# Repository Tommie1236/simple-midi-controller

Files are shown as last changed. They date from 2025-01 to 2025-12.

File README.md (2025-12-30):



# Simple MIDI Controller

### A simple 32-button MIDI controller with bank support, built around the RP2040 microcontroller (e.g., RP2040-Zero, but other RP2040 boards should work with appropriate pin changes). Designed for compatibility with any software that accepts USB MIDI input.
## Features

  32 configurable buttons
  Multiple banks for expanded control
  USB MIDI device class (works out-of-the-box with most DAWs and lighting control software)
  MAX7219 7-segment display for bank number
  LVGL graphics library integration for future graphical display support
  Example use: MyDMX, generic macropad for other MIDI-compatible software

## Hardware

  Primary target: RP2040-Zero
  Any RP2040-based board can be used (adjust pin mappings as needed)
  Wiring and assembly instructions: TODO!!

## Software Dependencies

  Raspberry Pi Pico SDK
  TinyUSB
  LVGL v9.4.0 (Light and Versatile Graphics Library)

## Building and Flashing

  Clone this repository and its dependencies.
  Build the firmware using the included build script in the root directory. 
  Optionally use the -l flag to automaticly use picotool to load it to the device.
  Or reboot into bootsel mode and drag the compiled binary(.uf2) onto the usb mass storage device. 

## Usage

Once flashed, the controller will appear as a standard USB MIDI device. It should work with any MIDI-compatible software. Currently tested with MyDMX, but suitable for general MIDI macro control.

For information about the LVGL graphics library integration, see [Code/LVGL_INTEGRATION.md](Code/LVGL_INTEGRATION.md).

Pin Configuration

  Default pin mappings are defined in the code for RP2040-Zero.
  If you use a different RP2040 board, update the pin definitions as needed in the source files.

## Roadmap

  - [x] implement segment display
  - [x] add banking support
  - [x] add LVGL graphics library for future graphical display/menu support
  - [ ] add a menu for configuration?
  - [ ] Add full hardware assembly and wiring instructions
  - [x] create pcb for easier replication without the big amount of soldering perfboard requires.
  - [x] ^ also schematic?
  
## Ai useage (hackclub Summer of Making)
I've used ai in this project. for example to create a base for this readme but i have also used some chatbots with high level debugging if i got stuck.
I've also had copilot enable in vscode when i started the project. but i've since switched to neovim and didn't add any ai or lsp yet. so mostly just high level debugging and writing text. (I'm very bad at this as you can probably already see.)
I really don't like using ai to generate code snippets. sometimes copilot is usefull when you need a lot of repeating code with just a simple parameter changing. But the rest of the time it is pretty useless imo and things like chatgpt/gemini make too many mistakes or inefficiencies to be usefull for snippets.

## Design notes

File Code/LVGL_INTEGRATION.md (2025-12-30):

# LVGL Integration for Simple MIDI Controller

This document describes the LVGL (Light and Versatile Graphics Library) integration for the Simple MIDI Controller project.

## Overview

LVGL v9.4.0 has been integrated into this project to provide graphical display capabilities. This integration provides a foundation for adding a graphical menu system and enhanced visual feedback beyond the MAX7219 7-segment display.

## Components

### 1. LVGL Library
- Added as a git submodule in `Code/lib/lvgl`
- Configured via `Code/lv_conf.h`
- Built as part of the main firmware build

### 2. Display Driver (`lvgl_display.c` / `lvgl_display.h`)
- Provides the interface between LVGL and display hardware
- Currently implements a stub driver that can be extended for actual display hardware
- Default resolution: 240x240 pixels (configurable in `lvgl_display.h`)
- Uses partial buffering for memory efficiency

### 3. UI Integration (`main.c`)
- LVGL initialization in `init_lvgl()`
- Periodic update via `lvgl_task()` called in main loop
- Example UI showing current bank number
- Bank number updates when bank buttons are pressed

## Configuration

The LVGL configuration file (`Code/lv_conf.h`) is optimized for the RP2040:

- **Color Depth**: 16-bit (RGB565)
- **Memory**: Uses standard C library malloc
- **Rendering**: Software rendering with no SIMD acceleration
- **Widgets**: Only essential widgets enabled (Label, Button, Arc, Bar, Image)
- **Demos/Examples**: Disabled to save flash space
- **Font**: Montserrat 14 enabled by default

## Memory Usage

The current firmware with LVGL uses approximately:
- Flash: 393KB (~18.76% of 2MB)
- RAM: 25KB (~9.85% of 256KB)

LVGL display buffers use approximately 4.8KB (2 buffers of 240x10 pixels @ 16bpp).

## Display Hardware Support

The stub display driver (`lvgl_display.c`) provides the framework for connecting actual display hardware. To add display support:

1. Implement the `disp_flush_cb()` function to send pixel data to your display
2. Add display initialization code in `lvgl_display_init()`
3. Configure display resolution in `lvgl_display.h` (`DISP_HOR_RES`, `DISP_VER_RES`)
4. Add required SPI/I2C/parallel interface code

### Supported Display Types
Common display controllers that can be integrated:
- **ST7789** - Popular 240x240 TFT LCD
- **ILI9341** - 320x240 TFT LCD
- **SSD1306** - 128x64 OLED (monochrome)
- **ST7735** - Small TFT LCDs

## API

### Display Initialization
```c
lv_display_t* lvgl_display_init(void);
```
Initializes LVGL and creates the display object.

### Display Task
```c
void lvgl_task(void);
```
Call this periodically (in main loop) to handle LVGL timers and rendering.

### Update Bank Display
```c
void lvgl_update_bank(uint8_t bank);
```
Updates the displayed bank number on the LVGL UI.

## Building

The build process automatically includes LVGL:

```bash
./build.sh
```

The ARM GCC compiler (`gcc-arm-none-eabi`) is required.

## Known Limitations

1. **No Physical Display**: The current implementation is a stub driver. No actual display hardware is connected.
2. **Helium ASM Disabled**: ARM Helium SIMD assembly optimizations are disabled (not supported on RP2040's Cortex-M0+).
3. **Limited Widgets**: Only essential widgets are enabled to conserve flash space.

## Future Enhancements

- Add support for specific display hardware (e.g., ST7789)
- Implement touch input handling
- Create more sophisticated UI for bank selection and settings
- Add configuration menu
- Implement display themes and animations

## Troubleshooting

### Build Errors

**"ARM Helium assembly errors"**: The helium assembly file has been disabled by renaming `lv_blend_helium.S` to `lv_blend_helium.S.disabled`. This is expected for RP2040.

**"lv_conf.h not found"**: Ensure `Code/lv_conf.h` exists and `LV_CONF_INCLUDE_SIMPLE` is defined properly.

### Runtime Issues

**"No visual output"**: This is expected - the stub driver doesn't output to actual hardware. Connect a physical display and implement the flush callback.

## Resources

- [LVGL Official Documentation](https://docs.lvgl.io/)
- [LVGL GitHub Repository](https://github.com/lvgl/lvgl)
- [RP2040 Datasheet](https://datasheets.raspberrypi.com/rp2040/rp2040-datasheet.pdf)

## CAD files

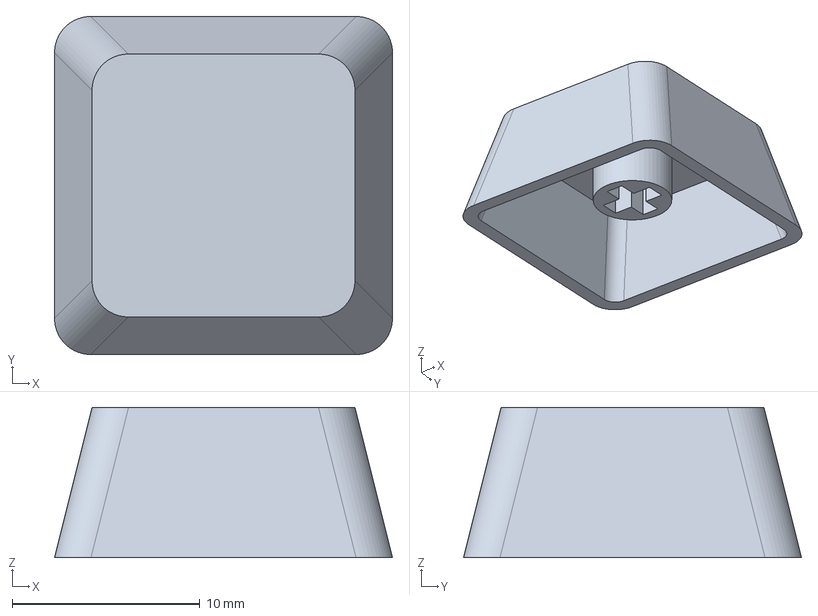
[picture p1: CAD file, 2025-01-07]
keycap 1u blank.FCStd
18.0 x 18.0 x 8.00 mm

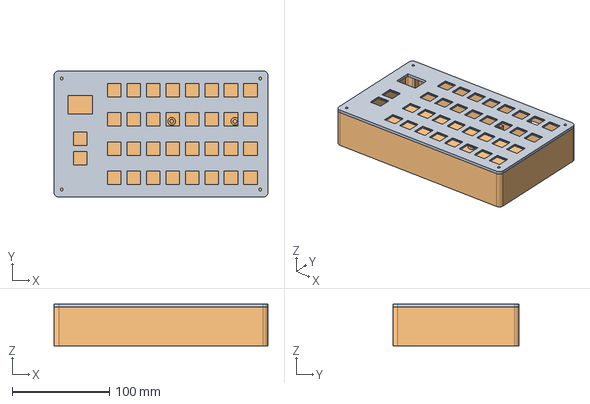
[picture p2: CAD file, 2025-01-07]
model.FCStd
220.0 x 130.0 x 43.0 mm
Faceplate

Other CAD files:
keycap-1u-blank.stl

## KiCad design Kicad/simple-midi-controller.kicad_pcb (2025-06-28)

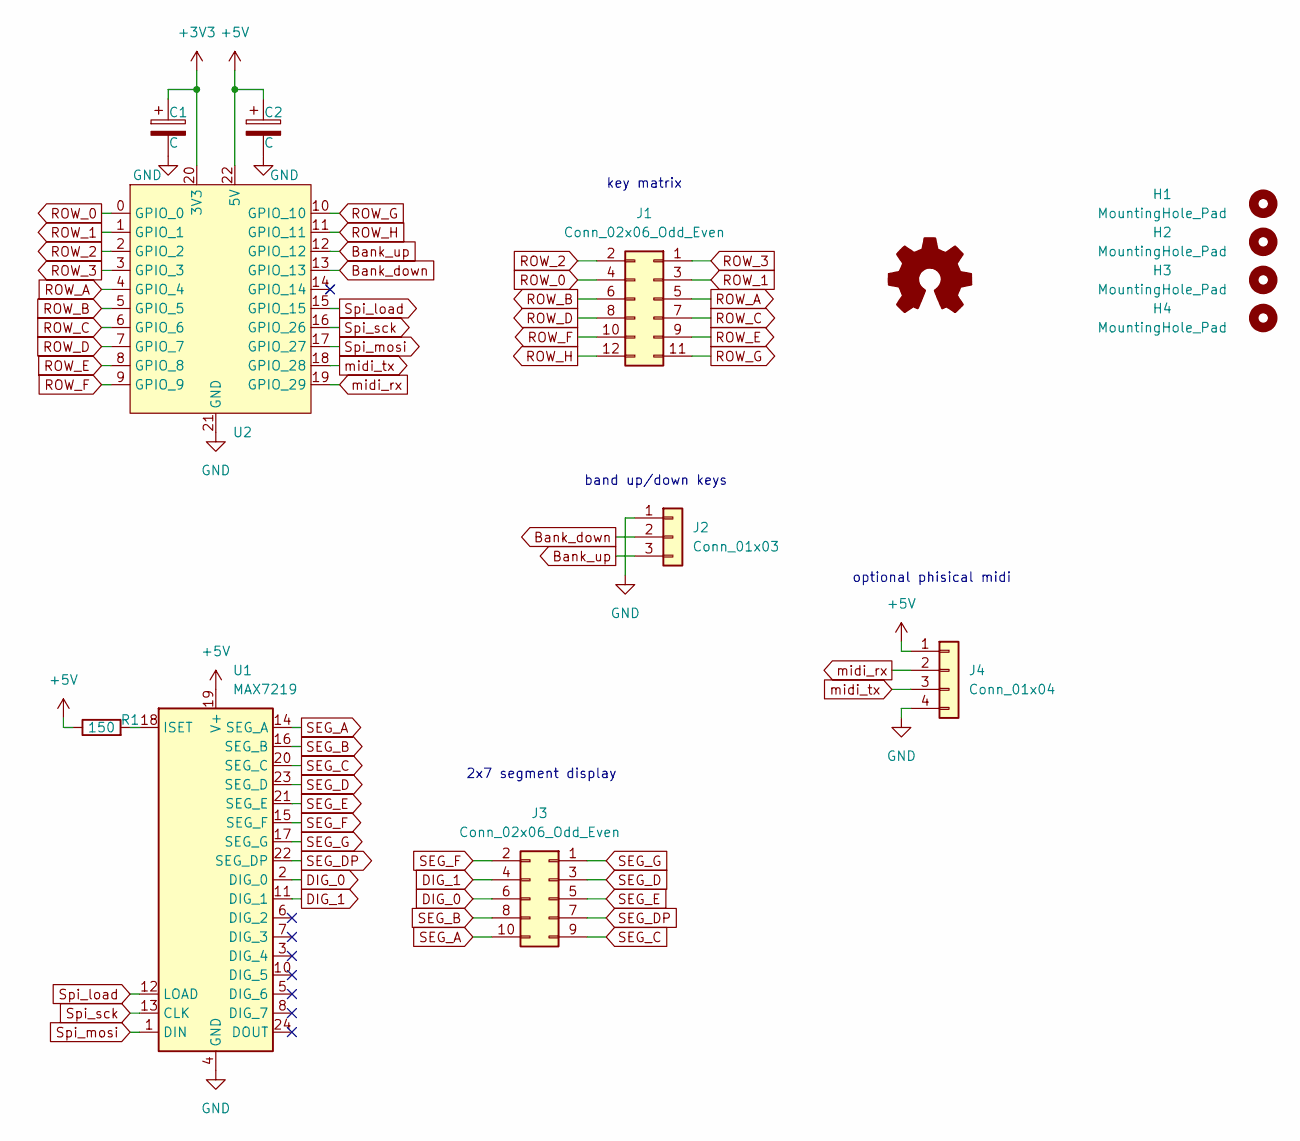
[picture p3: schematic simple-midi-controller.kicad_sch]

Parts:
C1, C2: C; CP_Radial_D5.0mm_P2.50mm
H1, H2, H3, H4: MountingHole_Pad; MountingHole_3.2mm_M3
J1: Conn_02x06_Odd_Even; PinHeader_2x06_P2.54mm_Vertical
J2: Conn_01x03; PinHeader_1x03_P2.54mm_Vertical
J3: Conn_02x06_Odd_Even; PinHeader_2x05_P2.54mm_Vertical
J4: Conn_01x04; PinHeader_1x04_P2.54mm_Vertical
R1: 150; R_Axial_DIN0207_L6.3mm_D2.5mm_P10.16mm_Horizontal
U1: MAX7219; DIP-24_W7.62mm_Socket
U2: RP2040-Zero

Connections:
+3V3: C1.1, U2.20 (3V3)
+5V: C2.1, J4.1, R1.1, U1.19 (V+), U2.22 (5V)
Bank_down: J2.2, U2.13 (GPIO_13)
Bank_up: J2.3, U2.12 (GPIO_12)
DIG_0: J3.6, U1.2 (DIG_0)
DIG_1: J3.4, U1.11 (DIG_1)
GND: C1.2, C2.2, J2.1, J4.4, U1.4 (GND), U1.9 (GND), U2.21 (GND)
unnamed: R1.2, U1.18 (ISET)
ROW_0: J1.4, U2.0 (GPIO_0)
ROW_1: J1.3, U2.1 (GPIO_1)
ROW_2: J1.2, U2.2 (GPIO_2)
ROW_3: J1.1, U2.3 (GPIO_3)
ROW_A: J1.5, U2.4 (GPIO_4)
ROW_B: J1.6, U2.5 (GPIO_5)
ROW_C: J1.7, U2.6 (GPIO_6)
ROW_D: J1.8, U2.7 (GPIO_7)
ROW_E: J1.9, U2.8 (GPIO_8)
ROW_F: J1.10, U2.9 (GPIO_9)
ROW_G: J1.11, U2.10 (GPIO_10)
ROW_H: J1.12, U2.11 (GPIO_11)
SEG_A: J3.10, U1.14 (SEG_A)
SEG_B: J3.8, U1.16 (SEG_B)
SEG_C: J3.9, U1.20 (SEG_C)
SEG_D: J3.3, U1.23 (SEG_D)
SEG_DP: J3.7, U1.22 (SEG_DP)
SEG_E: J3.5, U1.21 (SEG_E)
SEG_F: J3.2, U1.15 (SEG_F)
SEG_G: J3.1, U1.17 (SEG_G)
Spi_load: U1.12 (LOAD), U2.15 (GPIO_15)
Spi_mosi: U1.1 (DIN), U2.17 (GPIO_27)
Spi_sck: U1.13 (CLK), U2.16 (GPIO_26)
midi_rx: J4.2, U2.19 (GPIO_29)
midi_tx: J4.3, U2.18 (GPIO_28)

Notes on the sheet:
2x7 segment display
optional phisical midi
band up/down keys
key matrix

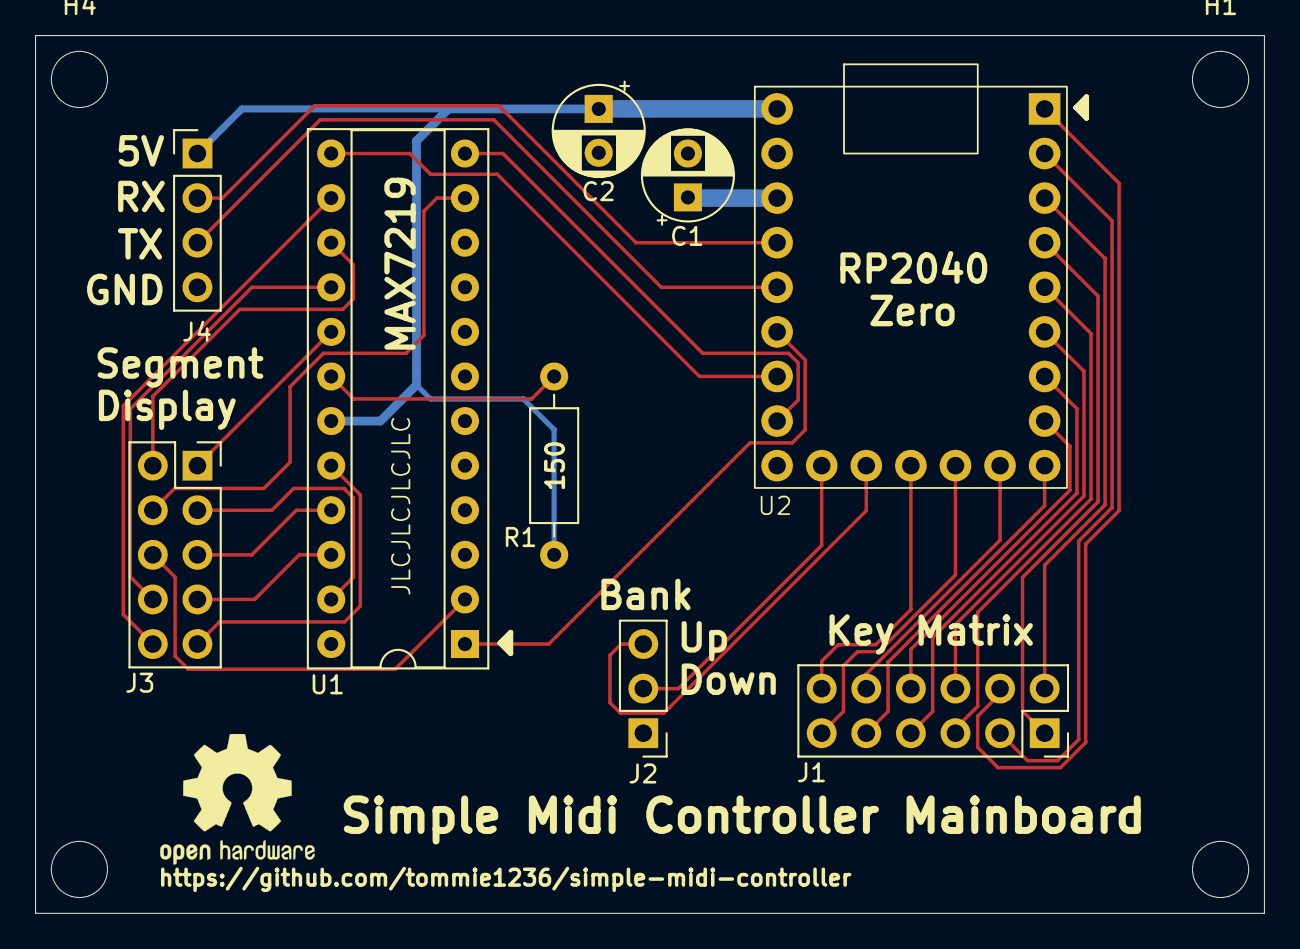
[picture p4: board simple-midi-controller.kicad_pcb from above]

Board: 2 copper layers, 70.0 x 50.0 mm, 13 parts (0 on the bottom side), 33 nets.

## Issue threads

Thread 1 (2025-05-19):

Improve matrix scannjng

Tommie1236, 2025-05-19:
I fucked up the direction of the diodes so for now it is scanning 8 collums by 4 rows.

So change the scanning with reverse current so it is 4 rows by 8 columns and should be about 2x faster

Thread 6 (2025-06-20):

Implement Segment Display

Tommie1236, 2025-06-20:
implement the build in segment display

TODO:
- [ ] complete hardware, mainly connections.
- [ ] figure out how the menu should look.

Tommie1236, 2025-06-28:
i broke the perfboard and don't really feel like fixing it. its a lot of work for something temporary. i have a pcb being made right now.

so i can continue with the segment display in about 1-2 weeks when i recieve the pcb.

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
(^ render is outdated but i don't have my laptop with me for a new render.)

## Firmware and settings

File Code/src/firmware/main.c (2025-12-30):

#include "main.h"

// rp2040 
#include "pico/stdlib.h"
#include "pico/binary_info.h"
#include "pico/time.h"
#include "pico/multicore.h"
#include "hardware/gpio.h"

// c/cpp 
#include <string.h> // memcpy
#include <stdio.h>

// tinyusb
#include "bsp/board.h"
#include "tusb.h"

#include "max7219_driver.h"

// lvgl
#include "lvgl.h"
#include "lvgl_display.h"


void midi_task();
void key_matrix_task();
void init_gpio();
void init_segment_display();
void init_lvgl();
void lvgl_task();
void lvgl_update_bank(uint8_t bank);
void init_physical_midi();
void check_debug();
void write_midi(uint8_t const* message, uint8_t length);

max7219_t display;

/* LVGL UI objects */
static lv_obj_t* bank_label = NULL;

uint8_t current_bank = 0;

uint32_t buttons_pressed = 0x00000000;
uint32_t previous_buttons_pressed = 0x00000000;

uint8_t last_midi_message[3];
uint32_t no_messages_send_count = 0;

const uint8_t row_pins[MATRIX_ROWS] = {ROW_0_PIN, ROW_1_PIN, ROW_2_PIN, ROW_3_PIN};


typedef enum {
    PRINT_PRESSED,
    DISPLAY_LAST_BUTTON,
    CONTINUOUS_MIDI,
    NUM_DEBUG_MODES
} Debug_Mode;

bool debug_settings[NUM_DEBUG_MODES];


void core1_main(){

    while (1){
        tud_task();
    }
};

void core0_main(){

    board_init(); 
    tusb_init();
    stdio_usb_init();

    init_gpio();
    init_segment_display();
    init_lvgl();

    multicore_launch_core1(&core1_main);

    check_debug();

    while(1) {
        key_matrix_task();
        midi_task();
        lvgl_task();
	};
};


int main() {
	
	core0_main();

    return 0;
}



void init_gpio() {

    gpio_init_mask(matrix_out_mask | matrix_in_mask);
    gpio_set_function_masked(matrix_out_mask | matrix_in_mask, GPIO_FUNC_SIO);

    gpio_set_dir_in_masked(matrix_in_mask); 

	for (uint pin = 0; pin < 32; ++pin) {
		if (matrix_in_mask & (1u << pin)) {
			gpio_pull_up(pin);
		}
	}

    gpio_set_dir_out_masked(matrix_out_mask);

    gpio_set_dir(BANK_UP_PIN, GPIO_IN);
    gpio_set_dir(BANK_DOWN_PIN, GPIO_IN); 
    gpio_pull_up(BANK_UP_PIN);
    gpio_pull_up(BANK_DOWN_PIN);

}

void init_segment_display() {

    max7219_init(&display,
                 MAX7219_SPI_PORT,
                 MAX7219_LOAD_PIN,
                 MAX7219_CLK_PIN,
                 MAX7219_MOSI_PIN,
                 MAX7219_NUM_SEGMENTS);

    max7219_set_decode_mode(&display, BCD_DECODE);

    max7219_display_number_2_digits(&display, 0);
};

void init_physical_midi () {
    // gpio_set_function(MIDI_TX_PIN, GPIO_FUNC_UART);
    // gpio_set_function(MIDI_RX_PIN, GPIO_FUNC_UART);
};

void write_midi(uint8_t const* message, uint8_t length) {

    #ifdef USB_MIDI_ENABLE
    tud_midi_n_stream_write(0, 0, message, length);
    #endif // USB_MIDI_ENABLE

    #ifdef PHY_MIDI_ENABLE
    // write phy midi
    #endif

}

void check_debug() {

    // also print these as active if set in header
    debug_settings[DISPLAY_LAST_BUTTON] = DEBUG_DISPLAY_LAST_BUTTON;
    debug_settings[PRINT_PRESSED] = DEBUG_PRINT_PRESSED;
    debug_settings[CONTINUOUS_MIDI] = DEBUG_CONTINUOUS_MIDI;

    // read keyboard for debug keys
    key_matrix_task();
    // printf("buttons: %08X \n", (int)buttons_pressed);

    if (buttons_pressed & 1) {
        debug_settings[DISPLAY_LAST_BUTTON] = true;
        printf("[DEBUG] DISPLAY_LAST_BUTTON Active\n");
    };
    if (buttons_pressed & (1 << 1)) {
        debug_settings[PRINT_PRESSED] = true;
        printf("[DEBUG] PRINT_PRESSED Active\n");
    };
    if (buttons_pressed & (1 << 2)) {
        debug_settings[CONTINUOUS_MIDI] = true;
        printf("[DEBUG] CONTINUOUS_MIDI Active\n");
    };
};

void midi_task() {

    uint8_t msg[3];
    uint32_t changed_buttons = buttons_pressed ^ previous_buttons_pressed;

    if (debug_settings[CONTINUOUS_MIDI]) {
        no_messages_send_count++;
        if (no_messages_send_count > 1000) {
            write_midi(last_midi_message, 3);
            no_messages_send_count = 0;
        };
    };
	
    if (debug_settings[PRINT_PRESSED]) {
        printf("buttons: %08X \n", (int)buttons_pressed);
    };

    // note on message (0x9X)
    // ored with the bank / 4 because a bank has 32 buttons and there are 128 notes per midi channel
    // so 4 banks per midi channel
    msg[0] = 0x90 | (current_bank / 4);

    for (int i = 0; i < 32; i++) {
        uint32_t mask = 1 << i;

        if (changed_buttons & mask) {
            
            msg[1] = i + ((current_bank % 4) * 32); 

            if (buttons_pressed & mask) {
                // Button pressed
                msg[2] = 127; // velocito / on

                if (debug_settings[PRINT_PRESSED]) {
                    printf("Button %d pressed\n", i);
                };

            } else {
                // Button released
                msg[2] = 0; // velocito / off
 
                if (debug_settings[PRINT_PRESSED]) {
                    printf("Button %d released\n", i);
                };               
            }

            write_midi(msg, 3);
            memcpy(last_midi_message, msg, sizeof(msg));
            no_messages_send_count = 0;

        }

    }

    previous_buttons_pressed = buttons_pressed;
}


static bool bank_up_last = true;
static bool bank_down_last = true;

void key_matrix_task() {

    bool bank_up_current = gpio_get(BANK_UP_PIN);
    bool bank_down_current = gpio_get(BANK_DOWN_PIN);

    if (!bank_up_current && bank_up_last) {
        if (current_bank == 63) {
            current_bank = 0;
        } else {
            current_bank++;
        }
        max7219_display_number_2_digits(&display, current_bank);
        lvgl_update_bank(current_bank);
    }

    if (!bank_down_current && bank_down_last) {
        if (current_bank == 0) {
            current_bank = 63;
        } else {
            current_bank--;
        }
        max7219_display_number_2_digits(&display, current_bank);
        lvgl_update_bank(current_bank);
    }

    bank_up_last = bank_up_current;
    bank_down_last = bank_down_current;


    // Switch high/low values of gpio read when connecting diodes in correct orientation.
    buttons_pressed = 0;

    for ( int row_idx = 0; row_idx < MATRIX_ROWS; ++row_idx) {
        
        gpio_set_mask(matrix_out_mask);

        gpio_put(row_pins[row_idx], 0);
        sleep_us(50);

        uint32_t gpio_state = gpio_get_all();

        uint8_t columns_byte = ~(uint8_t)((gpio_state & matrix_in_mask) >> 4 );
        columns_byte &= 0xFF;

        buttons_pressed |= ((uint8_t) columns_byte << (row_idx * MATRIX_COLS));
        gpio_put(row_pins[row_idx], 1);
    }

}


void init_lvgl() {
    /* Initialize LVGL */
    lv_init();
    
    /* Initialize display driver */
    lv_display_t* disp = lvgl_display_init();
    if (disp == NULL) {
        printf("Failed to initialize LVGL display\n");
        return;
    }
    
    /* Create a simple UI showing the bank number */
    lv_obj_t* scr = lv_screen_active();
    
    /* Create a label to show bank number */
    bank_label = lv_label_create(scr);
    lv_obj_set_style_text_font(bank_label, &lv_font_montserrat_14, 0);
    lv_label_set_text(bank_label, "Bank: 00");
    lv_obj_align(bank_label, LV_ALIGN_CENTER, 0, 0);
    
    printf("LVGL initialized\n");
}


void lvgl_task() {
    /* Handle LVGL timer and refresh tasks */
    lv_timer_handler();
}


void lvgl_update_bank(uint8_t bank) {
    if (bank_label != NULL) {
        char buf[16];
        snprintf(buf, sizeof(buf), "Bank: %02d", bank);
        lv_label_set_text(bank_label, buf);
    }
}

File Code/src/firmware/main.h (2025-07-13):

// Config made for a RP2040 Zero. (Pi pico in smaller form factor)
// For full pin functions see:
// https://datasheets.raspberrypi.com/rp2040/rp2040-datasheet.pdf
// (Section 1.4.3)
//      
//               ┏━━━━━┓              
//           ┏━━━┫     ┣━━━┓          
//        5V ┃◎  ┗━━━━━┛  ◎┃ GP0  row 3
//       Gnd ┃■           ◎┃ GP1  row 2
//       3V3 ┃◎           ◎┃ GP2  row 1
// rx   GP29 ┃◎           ◎┃ GP3  row 0
// tx   GP28 ┃◎           ◎┃ GP4  col A
// tx   GP27 ┃◎     □     ◎┃ GP5  col B
// sck  GP26 ┃◎     ┗GP16 ◎┃ GP6  col C
// cs   GP15 ┃◎           ◎┃ GP7  col D
//      GP14 ┃◎ ◎ ◎ ◎ ◎ ◎ ◎┃ GP8  col E
//           ┗━━━━━━━━━━━━━┛
//              ┃ ┃ ┃ ┃ ┗ GP9     col F
//              ┃ ┃ ┃ ┗ GP10      col G
//              ┃ ┃ ┗ GP11        col H
//              ┃ ┗ GP12          bank up
//              ┗ GP13            bank down
//
//  GP17-25 Are available via pads on the bottom side of the board.


#ifndef MAIN_H
#define MAIN_H

#include "pico/stdlib.h"

// Debug Modes, setting here turns the mode persistently on.
// Pressing the according key on boot turn debug mode on for that session.
// ONLY MEANT FOR EASIER DEVELOPMENT, Don't turn on in production compile
#define DEBUG_PRINT_PRESSED         0
#define DEBUG_DISPLAY_LAST_BUTTON   0
#define DEBUG_CONTINUOUS_MIDI       0

// Please don't change. this really simplified the code.
// TODO: may support remapping later.
#define MATRIX_ROWS                 4
#define MATRIX_COLS                 8

#define ROW_0_PIN                   0
#define ROW_1_PIN                   1
#define ROW_2_PIN                   2
#define ROW_3_PIN                   3

#define COL_A_PIN                   4
#define COL_B_PIN                   5
#define COL_C_PIN                   6
#define COL_D_PIN                   7
#define COL_E_PIN                   8
#define COL_F_PIN                   9
#define COL_G_PIN                   10
#define COL_H_PIN                   11

#define BANK_UP_PIN                 12
#define BANK_DOWN_PIN               13


#define MAX7219_NUM_SEGMENTS        2
#define MAX7219_SPI_PORT            spi1

#define MAX7219_LOAD_PIN              15
#define MAX7219_CLK_PIN             26
#define MAX7219_MOSI_PIN            27

// phiysical midi. maybe support later
#define USB_MIDI_ENABLE             true
#define PHY_MIDI_ENABLE             true 
#define PHY_MIDI_TX_PIN             28
#define PHY_MIDI_RX_PIN             29


const uint32_t matrix_out_mask =  (1 << ROW_0_PIN) | 
                                 (1 << ROW_1_PIN) | 
                                 (1 << ROW_2_PIN) | 
                                 (1 << ROW_3_PIN);

const uint32_t matrix_in_mask = (1 << COL_A_PIN) |
                                 (1 << COL_B_PIN) |
                                 (1 << COL_C_PIN) |
                                 (1 << COL_D_PIN) |
                                 (1 << COL_E_PIN) |
                                 (1 << COL_F_PIN) |
                                 (1 << COL_G_PIN) |
                                 (1 << COL_H_PIN);




#endif // MAIN_H

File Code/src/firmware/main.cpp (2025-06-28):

#include "main.h"

// rp2040 
#include "pico/stdlib.h"
#include "pico/binary_info.h"
#include "pico/time.h"
#include "pico/multicore.h"
#include "hardware/gpio.h"
#include "hardware/spi.h"

// c/cpp 
#include <unordered_map>

// tinyusb
#include "bsp/board.h"
#include "tusb.h"



void midi_task();
void key_matrix_task();
void segment_display_task();
void init_gpio();
void init_segment_display();
void init_phisical_midi();
void check_debug();

uint8_t current_bank = 0;

uint32_t tud_midi_n_stream_write(uint8_t itf, uint8_t cable_num, uint8_t const* buffer, uint32_t bufsize);  // vscode thinks this isn't defined, but is defined at compile and complies correctly. //TODO: remove when fixed or finished

uint32_t buttons_pressed = 0x00000000;
uint32_t previous_buttons_pressed = 0x00000000;

const uint8_t row_pins[MATRIX_ROWS] = {ROW_0_PIN, ROW_1_PIN, ROW_2_PIN, ROW_3_PIN};


enum class Debug_Mode {
    PRINT_PRESSED = DEBUG_PRINT_PRESSED,
    DISPLAY_LAST_BUTTON = DEBUG_DISPLAY_LAST_BUTTON,
    CONTINUES_MIDI = DEBUG_CONTINUES_MIDI,
    NUM_DEBUG_MODES
};

std::unordered_map<Debug_Mode, bool> debug_settings;


// TODO: change to new debug modes.
#if DEBUG_PRINT
#define debug_printf(format, ...) \
    do { \
        printf(format, ##__VA_ARGS__); \
    } while (0)
#else
#define debug_printf(format, ...) \
    do {} while (0)
#endif




void core1_main(){
    while (1){
        tud_task();
    }
};

void core0_main(){
    board_init(); 
    tusb_init();
    stdio_usb_init();

    init_gpio();
    // init_segment_display();

    multicore_launch_core1(&core1_main);

    check_debug();

    while(1) {
        key_matrix_task();
        midi_task();
        sleep_ms(1);
        //segment_display_task();
	};
};


int main() {
	
	core0_main();

    return 0;
}



void init_gpio() {
    gpio_init_mask(matrix_out_mask | matrix_in_mask);
    gpio_set_function_masked(matrix_out_mask | matrix_in_mask, GPIO_FUNC_SIO);
	// implement banks later
    //gpio_init(BANK_UP_PIN);
    //gpio_init(BANK_DOWN_PIN);

    gpio_set_dir_in_masked(matrix_in_mask); 
	for (uint pin = 0; pin < 32; ++pin) {
		if (matrix_in_mask & (1u << pin)) {

            // Change to pull down with diodes in correct orientation
			gpio_pull_up(pin);
		}
	}

    gpio_set_dir_out_masked(matrix_out_mask);

    gpio_set_dir(BANK_UP_PIN, GPIO_IN);
    gpio_set_dir(BANK_DOWN_PIN, GPIO_IN); 
    gpio_pull_up(BANK_UP_PIN);
    gpio_pull_up(BANK_DOWN_PIN);

}

void init_segment_display() {
    spi_init(MAX7219_SPI_PORT, 10000 * 1000); // 10MHz

    gpio_set_dir(MAX7219_CS_PIN, GPIO_OUT);
    gpio_set_function(MAX7219_CS_PIN, GPIO_FUNC_SIO);
    gpio_set_function(MAX7219_CLK_PIN, GPIO_FUNC_SPI);
    gpio_set_function(MAX7219_MOSI_PIN, GPIO_FUNC_SPI);
};

void init_phisical_midi () {
    // gpio_set_function(MIDI_TX_PIN, GPIO_FUNC_UART);
    // gpio_set_function(MIDI_RX_PIN, GPIO_FUNC_UART);
};

void check_debug() {
    // read keyboard for debug keys
    key_matrix_task();
    if (buttons_pressed & 1) {
        debug_settings[Debug_Mode::DISPLAY_LAST_BUTTON] = true;
        printf("[DEBUG] DISPLAY_LAST_BUTTON Active");
    } else if (buttons_pressed & (1 << 1)) {
        debug_settings[Debug_Mode::PRINT_PRESSED] = true;
        printf("[DEBUG] PRINT_PRESSED Active");
    } else if (buttons_pressed & (1 << 2)) {
        debug_settings[Debug_Mode::CONTINUES_MIDI] = true;
        printf("[DEBUG] CONTINUES_MIDI Active");
    };
};

void midi_task() {

    uint8_t msg[3];
    uint32_t changed_buttons = buttons_pressed ^ previous_buttons_pressed;
	
    // debug_printf("buttons: %08X \n", int(buttons_pressed));

    msg[0] = 0x90 | (current_bank / 4); 

    for (int i = 0; i < 32; i++) {
        uint32_t mask = 1 << i;

        if (changed_buttons & mask) {
            
            msg[1] = i + ((current_bank % 4) * 32); // Note number TODO: apply bank
            if (buttons_pressed & mask) {
                // Button pressed
                msg[2] = 127; // velocito / on
                debug_printf("Button %d pressed\n", i);
            } else {
                // Button released
                msg[2] = 0; // velocito / off
                debug_printf("Button %d released\n", i);
            }
            tud_midi_n_stream_write(0, 0, msg, 3);
        }

    }

    previous_buttons_pressed = buttons_pressed;
}


static bool bank_up_last = true;
static bool bank_down_last = true;

void key_matrix_task() {

    bool bank_up_current = gpio_get(BANK_UP_PIN);
    bool bank_down_current = gpio_get(BANK_DOWN_PIN);

    if (!bank_up_current & bank_up_last) {
        if (current_bank == 63) {
            current_bank = 0;
        } else {
            current_bank++;
        }
    }

    if (!bank_down_current & bank_down_last) {
        if (current_bank == 0) {
            current_bank = 63;
        } else {
            current_bank--;
        }
    }

    bank_up_last = bank_up_current;
    bank_down_last = bank_down_current;


    // Switch high/low values of gpio read when connecting diodes in correct orientation.
    buttons_pressed = 0;

    for ( int row_idx = 0; row_idx < MATRIX_ROWS; ++row_idx) {
        
        gpio_set_mask(matrix_out_mask);

        gpio_put(row_pins[row_idx], 0);
        sleep_us(50);

        uint32_t gpio_state = gpio_get_all();

        uint8_t columns_byte = ~(uint8_t)((gpio_state & matrix_in_mask) >> 4 );
        columns_byte &= 0xFF;

        buttons_pressed |= ((uint8_t) columns_byte << (row_idx * MATRIX_COLS));
        gpio_put(row_pins[row_idx], 1);
    }

}

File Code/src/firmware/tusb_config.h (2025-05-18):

/*
 * The MIT License (MIT)
 *
 * Copyright (c) 2019 Ha Thach (tinyusb.org)
 *
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
 */

#ifndef _TUSB_CONFIG_H_
#define _TUSB_CONFIG_H_

#ifdef __cplusplus
extern "C" {
#endif

//--------------------------------------------------------------------
// COMMON CONFIGURATION
//--------------------------------------------------------------------

// defined by compiler flags for flexibility
#ifndef CFG_TUSB_MCU
#error CFG_TUSB_MCU must be defined
#endif

#if CFG_TUSB_MCU == OPT_MCU_LPC18XX || CFG_TUSB_MCU == OPT_MCU_LPC43XX || CFG_TUSB_MCU == OPT_MCU_MIMXRT10XX || \
    CFG_TUSB_MCU == OPT_MCU_NUC505 || CFG_TUSB_MCU == OPT_MCU_CXD56
#define CFG_TUSB_RHPORT0_MODE     (OPT_MODE_DEVICE | OPT_MODE_HIGH_SPEED)
#else
#define CFG_TUSB_RHPORT0_MODE     OPT_MODE_DEVICE
#endif

#ifndef CFG_TUSB_OS
#define CFG_TUSB_OS                 OPT_OS_PICO
#endif

// CFG_TUSB_DEBUG is defined by compiler in DEBUG build
// #define CFG_TUSB_DEBUG           0

/* USB DMA on some MCUs can only access a specific SRAM region with restriction on alignment.
 * Tinyusb use follows macros to declare transferring memory so that they can be put
 * into those specific section.
 * e.g
 * - CFG_TUSB_MEM SECTION : __attribute__ (( section(".usb_ram") ))
 * - CFG_TUSB_MEM_ALIGN   : __attribute__ ((aligned(4)))
 */
#ifndef CFG_TUSB_MEM_SECTION
#define CFG_TUSB_MEM_SECTION
#endif

#ifndef CFG_TUSB_MEM_ALIGN
#define CFG_TUSB_MEM_ALIGN          __attribute__ ((aligned(4)))
#endif

//--------------------------------------------------------------------
// DEVICE CONFIGURATION
//--------------------------------------------------------------------

#ifndef CFG_TUD_ENDPOINT0_SIZE
#define CFG_TUD_ENDPOINT0_SIZE    64
#endif

//------------- CLASS -------------//
#define CFG_TUD_CDC             1
#define CFG_TUD_MSC             0
#define CFG_TUD_HID             0 
#define CFG_TUD_MIDI            1 
#define CFG_TUD_VENDOR          0

// MIDI FIFO size of TX and RX
#define CFG_TUD_MIDI_RX_BUFSIZE   (TUD_OPT_HIGH_SPEED ? 512 : 64)
#define CFG_TUD_MIDI_TX_BUFSIZE   (TUD_OPT_HIGH_SPEED ? 512 : 64)

#define CFG_TUD_CDC_TX_BUFSIZE	64
#define CFG_TUD_CDC_RX_BUFSIZE	64
#define CFG_TUD_CDC_EP_BUFSIZE  64

#ifdef __cplusplus
}
#endif

#endif /* _TUSB_CONFIG_H_ */

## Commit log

2024-12-25 started model and project
    [model.FCStd]
2024-12-26 almost finished faceplate.
    realised it won't fit in my printer so need to redesign
    [model.FCStd]
2024-12-26 finished faceplate for real
    [model.FCStd]
2025-01-06 added pico sdk
2025-01-07 updated model
    [keycap 1u blank.FCStd, keycap-1u-blank.stl, model.FCStd]
2025-02-20 fixed key matrix scanning and broke midi
    [main.cpp, main.h, tusb_config.h]
2025-02-25 tried some more but usb not worky worky on win
    [tusb_config.h]
2025-05-18 disabled blocking matrix scanning code and fixed usb connection for windows
    [main.cpp, tusb_config.h]
2025-06-04 replaced forgotten temp var from so
    [main.cpp]
2025-06-19 fixed windows freezes and changed device name to something proper
    [main.cpp]
2025-06-23 fixed typo continues -> continuous
    [main.cpp, main.h]
2025-06-23 changed unordered map with c style array and fixed some bugs
    [main.cpp, main.h]
2025-06-24 this should fix debug modes but i broke the hardware so can't reliably test
    [main.cpp]
2025-06-25 created pcb
    [simple-midi-controller-B_Cu.gbr, simple-midi-controller-B_Mask.gbr, simple-midi-controller-B_Paste.gbr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]
2025-06-27 fixed duplicate bank variable
    [main.cpp]
2025-06-27 updated pcb design
    [simple-midi-controller-B_Cu.gbr, simple-midi-controller-B_Mask.gbr, simple-midi-controller-B_Paste.gbr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]
2025-06-28 reworked bank switching
2025-07-09 fixed wireing and updated header
    [main.h]
2025-07-11 first version of segment driver working
2025-07-12 now very working led driver and integrated it into the main code
2025-07-13 bunch of small fixes/improvements and optimizations
    [main.c]
2025-12-30 Add LVGL library support with basic display driver and UI
2025-12-30 Fix spelling errors and documentation inconsistencies
    [main.c]
